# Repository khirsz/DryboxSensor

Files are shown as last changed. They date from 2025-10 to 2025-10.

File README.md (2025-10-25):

# DryboxSensor
Battery powered filament drybox humidity sensor

Humidity and temperature is detected by ATH10 sensor. Data is displayed on SSD1306 OLED display. TP4056 module is used to charge 18650 battery cell. Additionally some buzzer and button are needed. I used Arudino Pro Mini, but any 3.3V level Arduino board should be fine.

Sensor most of the time works in low power mode. If hight humidity or low power voltage is detected, then alarm with buzzer is triggered. 

To improve power efficiency of the system desolder Arduino power LED and add 200Ohm resistor in series on negative side of active buzzer.

Check housing directory for 3D printed case project designed in FreeCad.

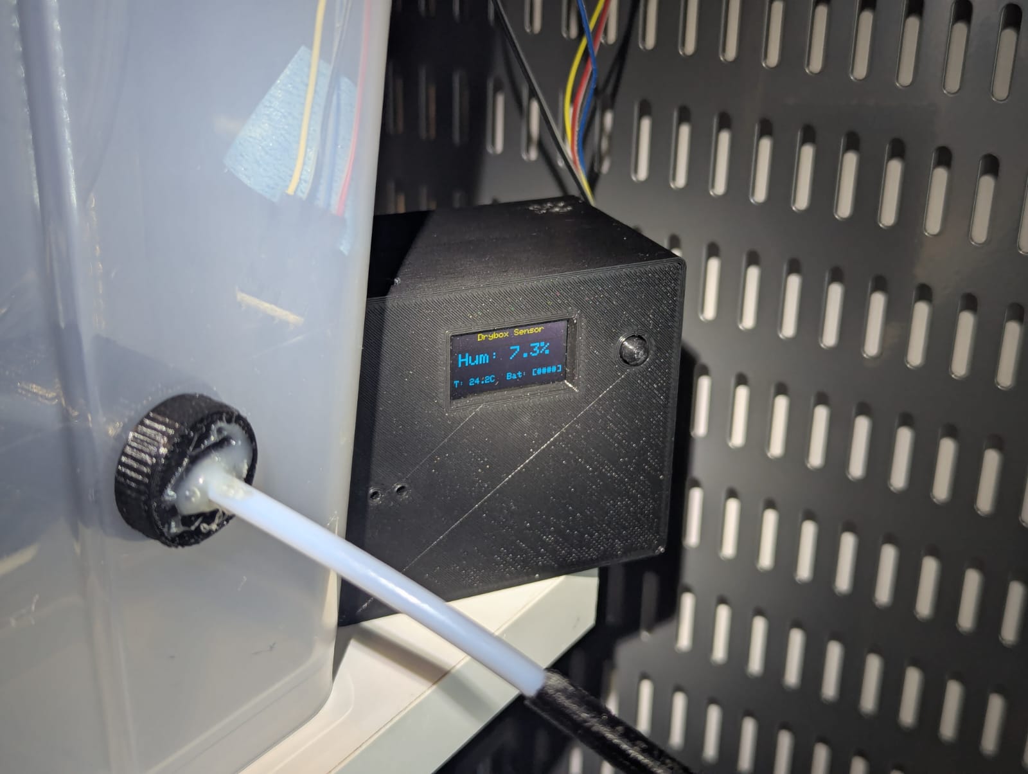
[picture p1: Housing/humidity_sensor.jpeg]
Housing


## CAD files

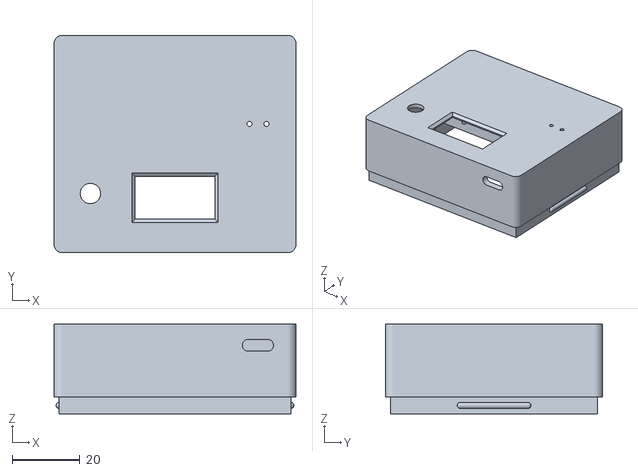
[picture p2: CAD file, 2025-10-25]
Housing/humidty_sensor-bottom.stl
71.5 x 64.2 x 26.5

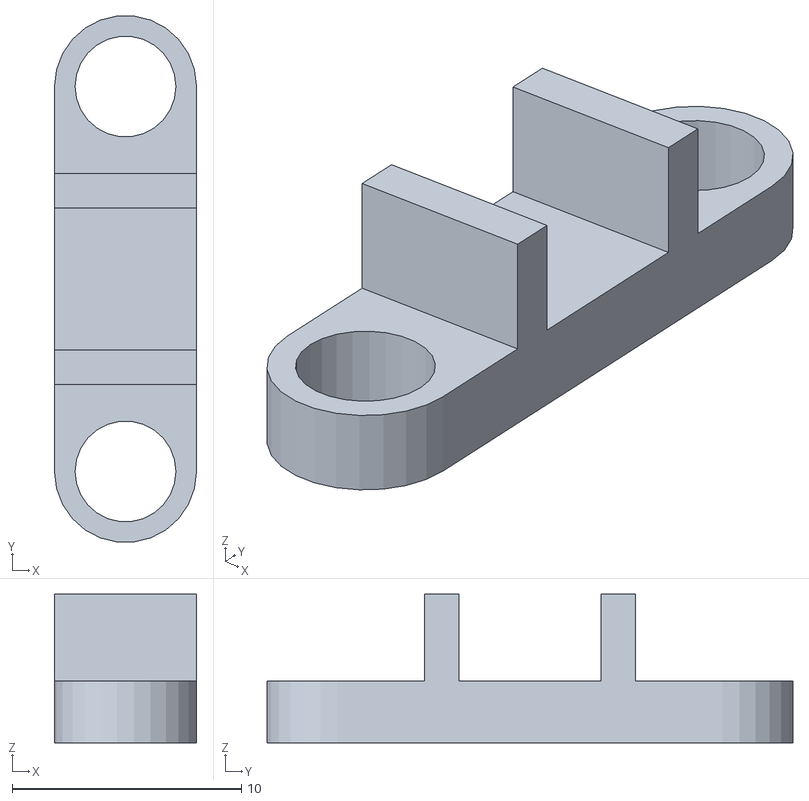
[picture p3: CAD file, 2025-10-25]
Housing/humidty_sensor-button.stl
6.20 x 23.0 x 6.50

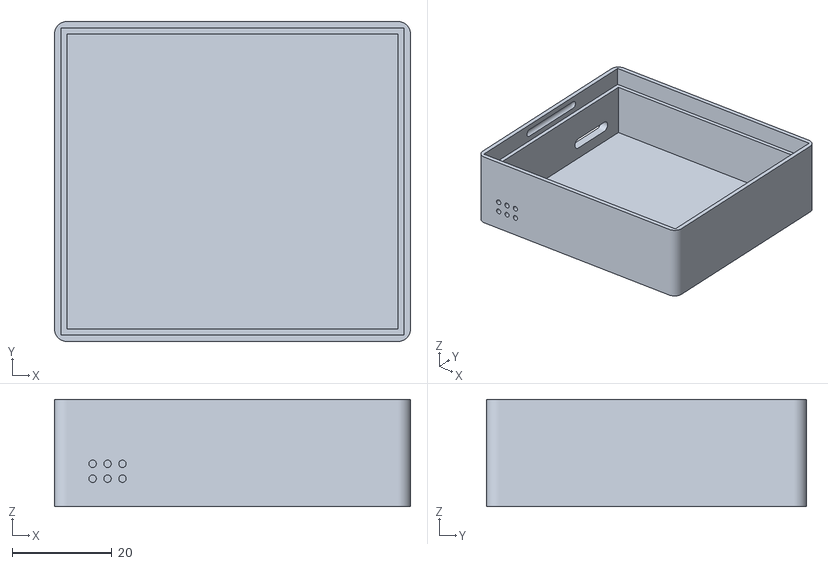
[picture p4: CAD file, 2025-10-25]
Housing/humidty_sensor-top.stl
71.5 x 64.2 x 21.5

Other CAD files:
Housing/humidty_sensor.FCStd

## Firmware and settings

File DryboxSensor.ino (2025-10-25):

#include <Adafruit_AHTX0.h>
#include <Adafruit_SSD1306.h>
#include <LowPower.h>

/// Battery definitions ///

static constexpr auto INTERNAL_VREF_MV = 1100L;  // Needs to be calibrated

static constexpr auto BAT_MAX_MV = 3800L;
static constexpr auto BAT_MIN_MV = 3000L;
static constexpr auto BAT_ALARM_MV = 3100L;

static constexpr auto BAT_LEVELS = 4;

/// Misc definitions ///

static constexpr auto DISPLAY_OFF_TIME = 10000UL;
static constexpr auto HELLO_TIME = 2000UL;
static constexpr auto HUMIDITY_ALARM_LEVEL = 30.0f;

//#define DEBUG

/// Pin definitions ///

// Button pin needs low pass filter for debuncing (100nF + 1KOhm), because it is used as an interrupt trigger
static constexpr auto BUTTON_PIN = 2;
static constexpr auto BUZZER_PIN = 3;

/// Sensor definitions ///

Adafruit_AHTX0 aht;

/// OLED definitions ///

static constexpr auto SCREEN_WIDTH = 128;  // OLED display width, in pixels
static constexpr auto SCREEN_HEIGHT = 64;  // OLED display height, in pixels

// Declaration for an SSD1306 display connected to I2C (SDA, SCL pins)
static constexpr auto OLED_RESET = -1;  // Reset pin # (-1 if sharing Arduino reset pin)
Adafruit_SSD1306 display(SCREEN_WIDTH, SCREEN_HEIGHT, &Wire, OLED_RESET);

/// State machine definitions ///
enum class SensorState : uint8_t { displayInit = 0,
                                   displayOn,
                                   lowPower,
                                   alarmCheck,
                                   alarmOn,
                                   alarmOnBlink };

enum class AlarmType : uint8_t { noAlarm = 0,
                                 humidityAlarm,
                                 batAlarm };

volatile static bool buzzerOff = false;
volatile SensorState state = SensorState::displayInit;

struct DisplayData {
  float humidity;
  float temp;
  long voltage;
  bool hideHumidity;
  bool hideBat;
};

/// Funcions ///

void displayError(const char* msg) {
  display.clearDisplay();
  display.setTextSize(1);
  display.setCursor(0, 25);
  display.print(F("Error: "));
  display.print(msg);
  display.display();
}

void displayLogo() {
  display.setCursor(9, 25);
  display.print(F("DryBox Sensor V1.0"));
  display.display();
  delay(HELLO_TIME);
  display.clearDisplay();
}

void displayTitle() {
  display.setTextSize(1);
  display.setCursor(27, 0);
  display.print(F("Drybox Sensor"));
}

void displayHumidity(float humidity, bool hideValue = false) {
  display.setTextSize(2);
  display.setCursor(5, 18);
  display.print(F("Hum: "));

  if (!hideValue) {
    display.print(humidity, 1);
    display.print("%");
  }
}

void displayTemp(float temp) {
  display.setTextSize(1);
  display.setCursor(0, 48);
  display.print(F("T: "));
  display.print(temp, 1);
  display.print("C");
}

void displayBat(int voltage, bool hideValue = false) {
  display.setTextSize(1);
  display.setCursor(62, 48);
  display.print(F("Bat: "));

  if (!hideValue) {
    display.print("[");
    auto level = calculateBatLevel(voltage);
    for (auto i = 0; i < BAT_LEVELS; i++) {
      if (i <= level) {
        display.print("#");
      } else {
        display.print(" ");
      }
    }
    display.print("]");
  }
}

void displayMainScreen(const DisplayData& displayData) {
  display.clearDisplay();
  displayTitle();
  displayHumidity(displayData.humidity, displayData.hideHumidity);
  displayTemp(displayData.temp);
  displayBat(displayData.voltage, displayData.hideBat);
  display.display();
}

int calculateBatLevel(long voltage) {
  int level = map(voltage, BAT_MIN_MV, BAT_MAX_MV, 0, BAT_LEVELS);
  return (level < BAT_LEVELS) ? level : (BAT_LEVELS - 1);
}

void initAlarm() {
  display.ssd1306_command(SSD1306_DISPLAYON);
  buzzerOff = false;
  state = SensorState::alarmOn;
}

void buttonInterrupt() {
  if (state >= SensorState::alarmOn) {
    buzzerOff = true;
#ifdef DEBUG
    Serial.println(F("ISR: Buzzer off"));
#endif
  } else {
    state = SensorState::displayInit;
#ifdef DEBUG
    Serial.println(F("ISR: Display init"));
#endif
  }
}

long readVcc() {
  long result;
  // Read 1.1V reference against AVcc
  ADMUX = _BV(REFS0) | _BV(MUX3) | _BV(MUX2) | _BV(MUX1);
  delay(2);             // Wait for Vref to settle
  ADCSRA |= _BV(ADSC);  // Convert
  while (bit_is_set(ADCSRA, ADSC)) {};
  result = ADCL;
  result |= ADCH << 8;
  result = INTERNAL_VREF_MV * 1024L / result;  // Back-calculate AVcc in mV
  return result;
}

/// Setup ///

void setup() {
#ifdef DEBUG
  Serial.begin(115200);
  Serial.println(F("DryBox Humidity sensor"));
#endif

  pinMode(BUZZER_PIN, OUTPUT);
  digitalWrite(BUZZER_PIN, LOW);

  pinMode(BUTTON_PIN, INPUT_PULLUP);
  attachInterrupt(digitalPinToInterrupt(BUTTON_PIN), buttonInterrupt, FALLING);

  display.begin(SSD1306_SWITCHCAPVCC, 0x3C);
  display.clearDisplay();
  display.setTextColor(WHITE);

  displayLogo();

  if (!aht.begin()) {
#ifdef DEBUG
    Serial.println(F("Could not find AHT? Check wiring"));
#endif
    displayError("AHT not found!");
    while (1) { delay(500); };
  }
#ifdef DEBUG
  Serial.println(F("AHT10 or AHT20 found"));
#endif
}

/// Main loop ///

void loop() {
  static unsigned long displayOnTimeStamp;
  static AlarmType alarmType = AlarmType::noAlarm;

  auto vcc = readVcc();
  sensors_event_t humidity, temp;
  aht.getEvent(&humidity, &temp);  // populate temp and humidity objects with fresh data

  DisplayData displayData{ humidity.relative_humidity, temp.temperature, vcc, false, false };

#ifdef DEBUG
  /*Serial.print(F("Temperature: "));
  Serial.print(temp.temperature);
  Serial.println(F(" degrees C"));
  Serial.print(F("Humidity: "));
  Serial.print(humidity.relative_humidity);
  Serial.println(F("% rH"));*/

  Serial.print(F("State: "));
  Serial.println(static_cast<uint8_t>(state));
#endif

  switch (state) {
    case SensorState::displayInit:
      display.ssd1306_command(SSD1306_DISPLAYON);
      displayOnTimeStamp = millis();
      state = SensorState::displayOn;
      break;

    case SensorState::displayOn:
      displayMainScreen(displayData);
      if (millis() - displayOnTimeStamp > DISPLAY_OFF_TIME) {
        display.ssd1306_command(SSD1306_DISPLAYOFF);
        state = SensorState::lowPower;
      }
      break;

    case SensorState::lowPower:
      state = SensorState::alarmCheck;
      LowPower.powerStandby(SLEEP_8S, ADC_OFF, BOD_OFF);
      break;

    case SensorState::alarmCheck:
      if (humidity.relative_humidity > HUMIDITY_ALARM_LEVEL) {
        initAlarm();
        alarmType = AlarmType::humidityAlarm;
      } else if (vcc < BAT_ALARM_MV) {
        initAlarm();
        alarmType = AlarmType::batAlarm;
      } else {
        state = SensorState::lowPower;
      }
      break;

    case SensorState::alarmOn:
      displayMainScreen(displayData);
      if (!buzzerOff) {
        digitalWrite(BUZZER_PIN, HIGH);
      }
      state = SensorState::alarmOnBlink;
      break;

    case SensorState::alarmOnBlink:
      displayData.hideHumidity = (alarmType == AlarmType::humidityAlarm) ? true : false;
      displayData.hideBat = (alarmType == AlarmType::batAlarm) ? true : false;
      displayMainScreen(displayData);
      digitalWrite(BUZZER_PIN, LOW);
      state = SensorState::alarmOn;
      break;
  }

#ifdef DEBUG
  Serial.print(F("Vcc value: "));
  Serial.print(vcc);
  Serial.println(F("mV"));

  Serial.print(F("Bat level: "));
  Serial.println(calculateBatLevel(vcc));
#endif

  delay(1000);
}

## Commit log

2024-06-29 Add low battery alarm
2025-10-25 Add 3D housing model
    [humidty_sensor.FCStd]
2025-10-25 Add info about housing
2025-10-25 Add missing files
    [humidty_sensor-bottom.stl, humidty_sensor-button.stl, humidty_sensor-top.stl]
